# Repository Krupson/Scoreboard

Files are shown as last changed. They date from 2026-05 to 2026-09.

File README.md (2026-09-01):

# Scoreboard
An open-sourced project of digital 3D-printed scoreboard based on ESP32C6 and some WS2812 LEDs.

## Features
- Configurable colors and brightness
- Current state memory (score does not reset on power loss)
- Debounced buttons (prevents accidental add/subtract score 2nd time in very short period)
- Remote control over WiFi (Work in progress)

## Controls
### Control score
Click Tx_ADD and Tx_SUB buttons once to control score for choosen team.

### Switch sides
Double click SWITCH_SIDES button to switch sides of team 1 and team 2.

### Reset score
Double click RESET_SCORE.

## Config mode
In order to enter config mode long press SWITCH_SIDES button. While in config mode there will be "0000" displayed on the board. In order to exit config mode (and save new settings) long press SWITCH_SIDES again.

### Change brightness
While in config mode you can press and hold T1_ADD / T1_SUB buttons to increase or decrease brightness of the display.

### Change team color
While in config mode you can press Tx_ADD / Tx_SUB to change color for choosen team. Red and green should be the least power-hungry :)

## Roadmap
This project was started as something intended for our internal use. Since I am designing 3D models for this project in Fusion360 and I am beginner with this software - quality of the project is much less than acceptable. Honestly I think that the whole 3D model part needs to be recreated from scratch with use of components, project variables for some dimensions etc. 

In near future I am planning to export all STLs I have right now and create Bambu Studio project with all the parts needed to be printed split into buildplates. Then I would like to focus on firmware part, create new PCB design with its own battery and charging module (currently we use old powerbank for providing power to the device).

### Things to be done
#### General
- Create docs with parts needed to build the scoreboard
- Cleanup repo

#### 3D models
- Recreate from scratch

#### Firmware
- Get rid of Arduino project, move everything to PlatformIO project
- Review RTOS code
- Finish remote control server
- Create remote control client firmware
- Add support for temperature and humidity sensors
- Add support for SD card logging (score + temp + hum over time)

#### PCB
- Add temperture and humidity sensor
- Add SD card slot
- Add support for battery

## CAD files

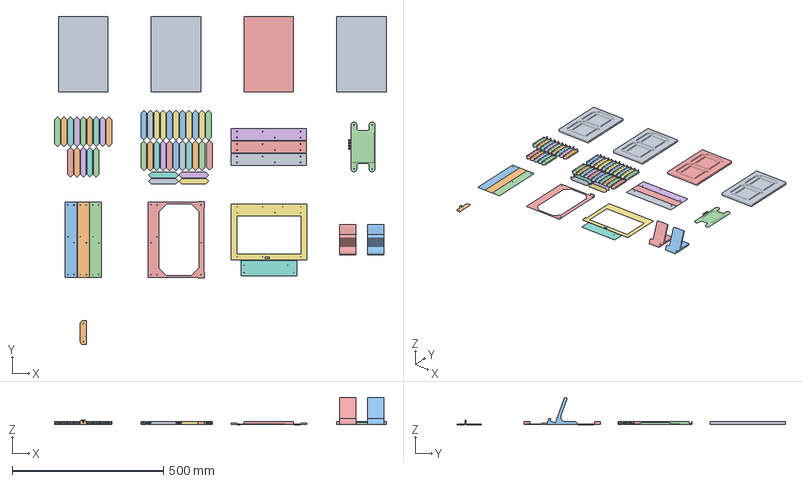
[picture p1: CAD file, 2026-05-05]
3d/Scoreboard.3mf
1098.7 x 1086.9 x 90.0 mm
Tablica wyników_Tablica wyników_Cyfra lewa.stl
antena.stl
Tablica wyników stojak_Tablica wyników_Body20.stl x 2
Tablica wyników_Tablica wyników_Obudowa sterownika.stl
dystans2_Tablica wyników_Body14.stl x 4
Tablica wyników_Tablica wyników_Szablon początek bottom.stl
Tablica wyników_Tablica wyników_Szablon kolejny bottom.stl
blenda 7seg_Tablica wyników_Blenda.stl x 40
Tablica wyników_Tablica wyników_Cyfra prawa.stl
Tablica wyników_Tablica wyników_Cyfra środek.stl
Tablica wyników_Tablica wyników_Cyfra środek sterownik.stl
Tablica wyników_Tablica wyników_Łącznik tymczasowy.stl x 3
łącznik top.stl x 3
szablon start.stl

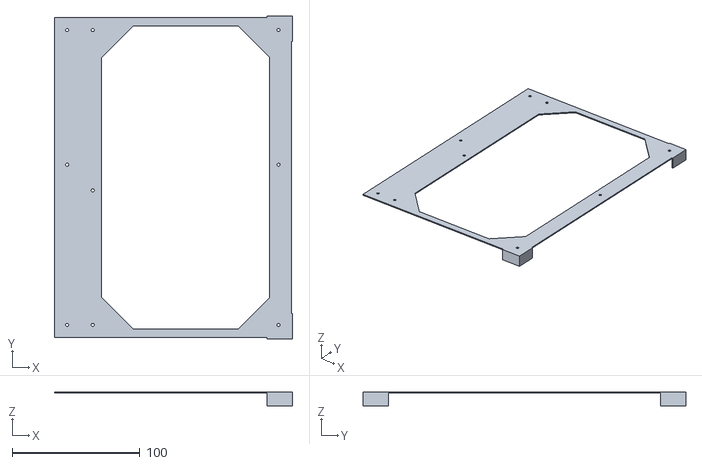
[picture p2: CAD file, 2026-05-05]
3d/stls/Scoreboard_Tablica wyników_Szablon początek top.stl
186.3 x 252.6 x 11.0

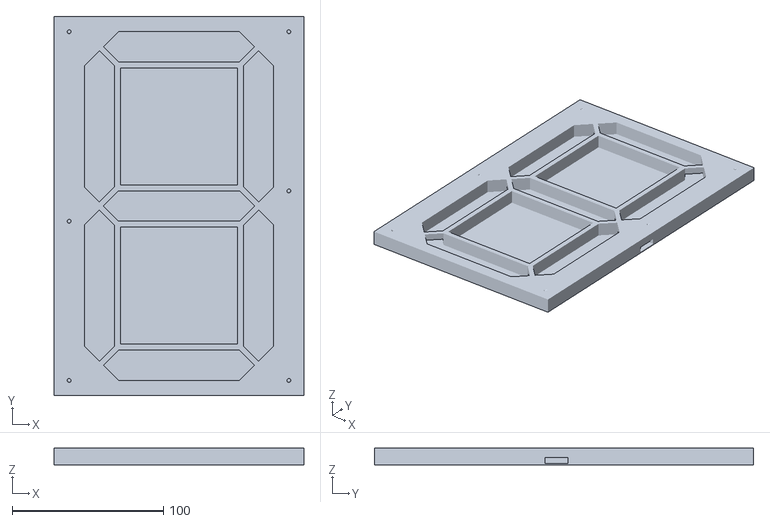
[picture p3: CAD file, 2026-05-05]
3d/stls/Scoreboard_Tablica wyników_Cyfra lewa.stl
165.3 x 250.6 x 11.0

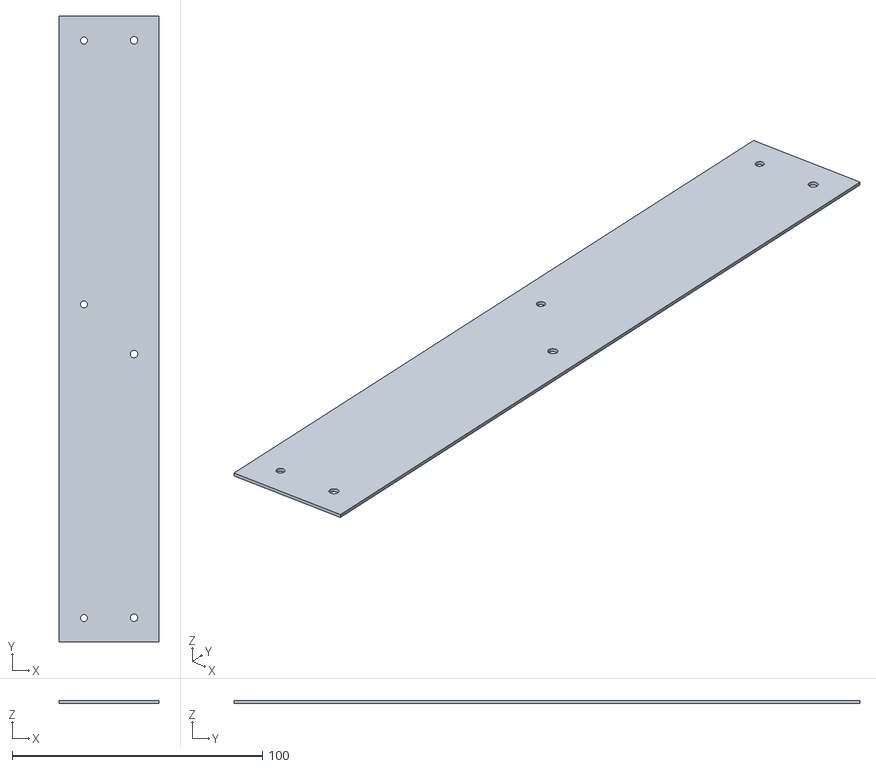
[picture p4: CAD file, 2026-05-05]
3d/stls/Scoreboard_Tablica wyników_Body15.stl
40.0 x 250.0 x 1.00

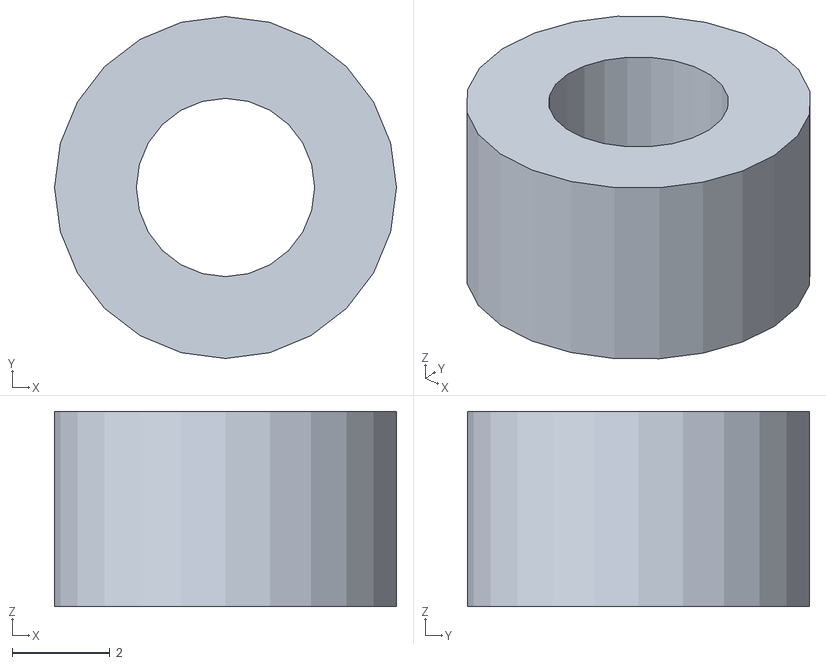
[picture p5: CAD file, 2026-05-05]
3d/stls/Scoreboard_Tablica wyników_Body12.stl
7.00 x 7.00 x 4.00

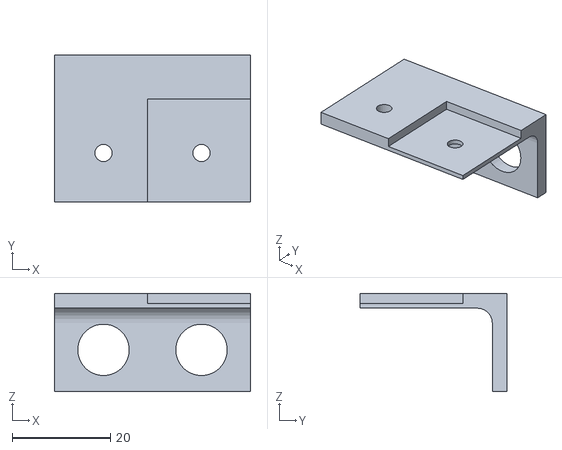
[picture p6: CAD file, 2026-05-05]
3d/stls/Scoreboard_Tablica wyników_Body22.stl
40.0 x 30.0 x 20.0

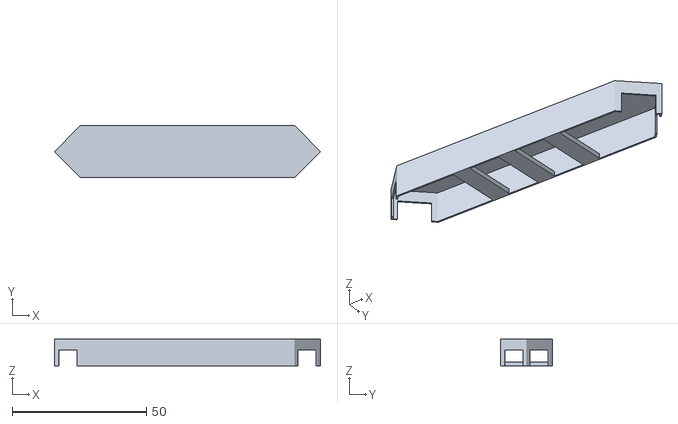
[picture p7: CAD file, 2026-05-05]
3d/stls/Scoreboard_Tablica wyników_Blenda.stl
99.2 x 19.4 x 10.0

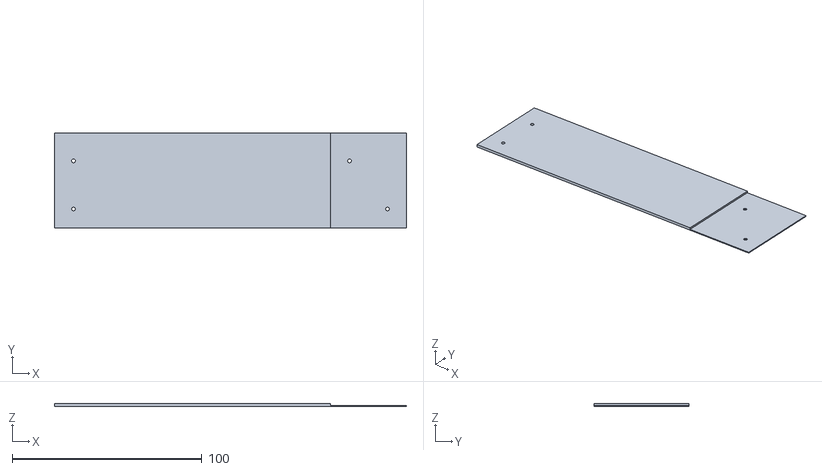
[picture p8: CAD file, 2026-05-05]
3d/stls/Scoreboard_Tablica wyników_Szablon kolejny bottom.stl
185.3 x 50.0 x 1.50

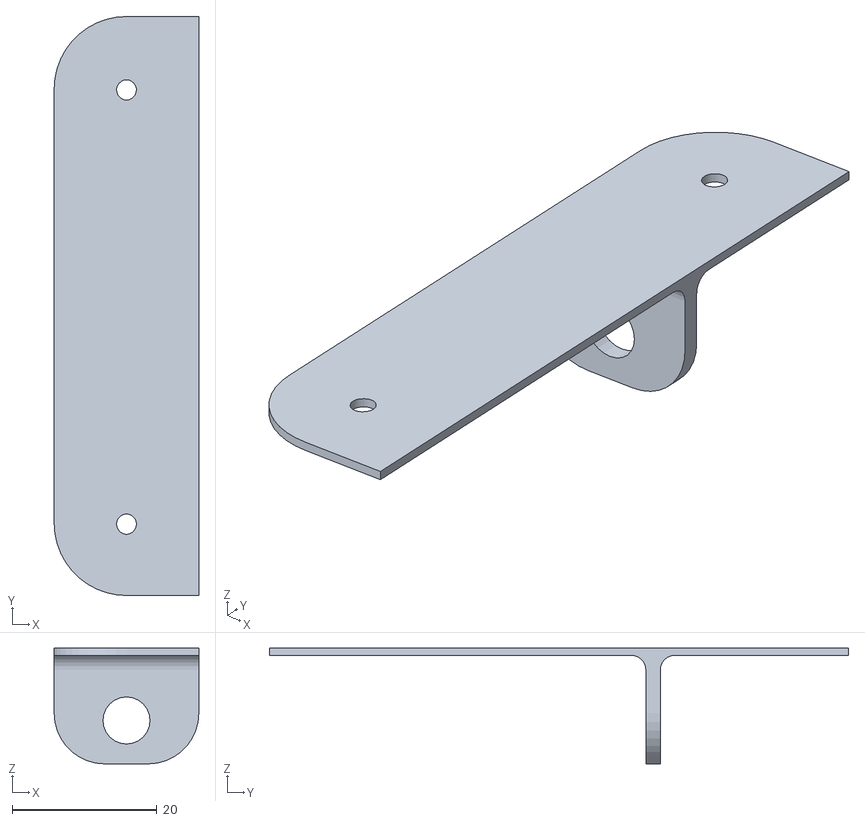
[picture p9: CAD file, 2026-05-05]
3d/stls/Scoreboard_Tablica wyników_Holder anteny.stl
20.0 x 80.0 x 16.0

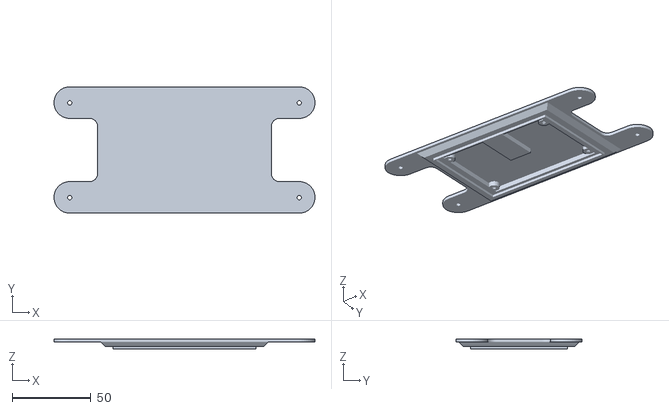
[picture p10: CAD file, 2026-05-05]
3d/stls/Scoreboard_Tablica wyników_Obudowa sterownika.stl
165.2 x 80.0 x 6.55

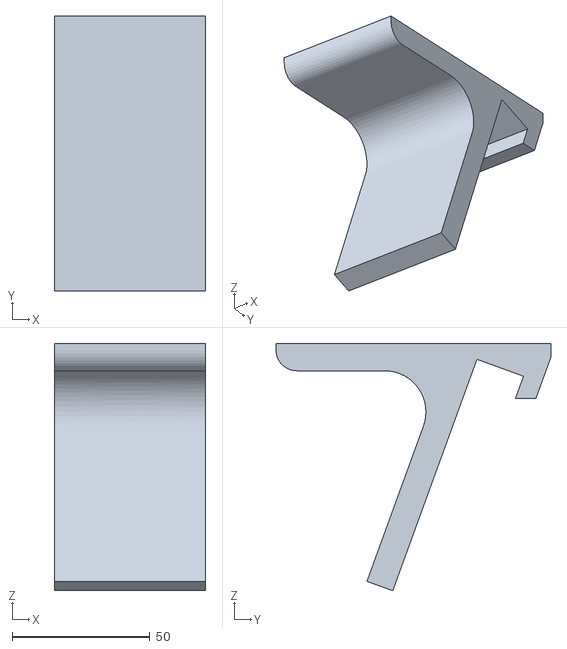
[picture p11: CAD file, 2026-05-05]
3d/stls/Scoreboard_Tablica wyników_Stojak.stl
55.0 x 100.0 x 90.0

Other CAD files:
3d/stls/Scoreboard_Tablica wyników_Body13.stl
3d/stls/Scoreboard_Tablica wyników_Cyfra środek.stl
3d/stls/Scoreboard_Tablica wyników_Cyfra środek sterownik.stl
3d/stls/Scoreboard_Tablica wyników_Body14.stl
3d/stls/Scoreboard_Tablica wyników_Cyfra prawa.stl
3d/stls/Scoreboard_Tablica wyników_Łącznik tymczasowy.stl
3d/stls/Scoreboard_Tablica wyników_Body11.stl
3d/Scoreboard.f3d
3d/stls/Scoreboard_Tablica wyników_Szablon początek bottom.stl

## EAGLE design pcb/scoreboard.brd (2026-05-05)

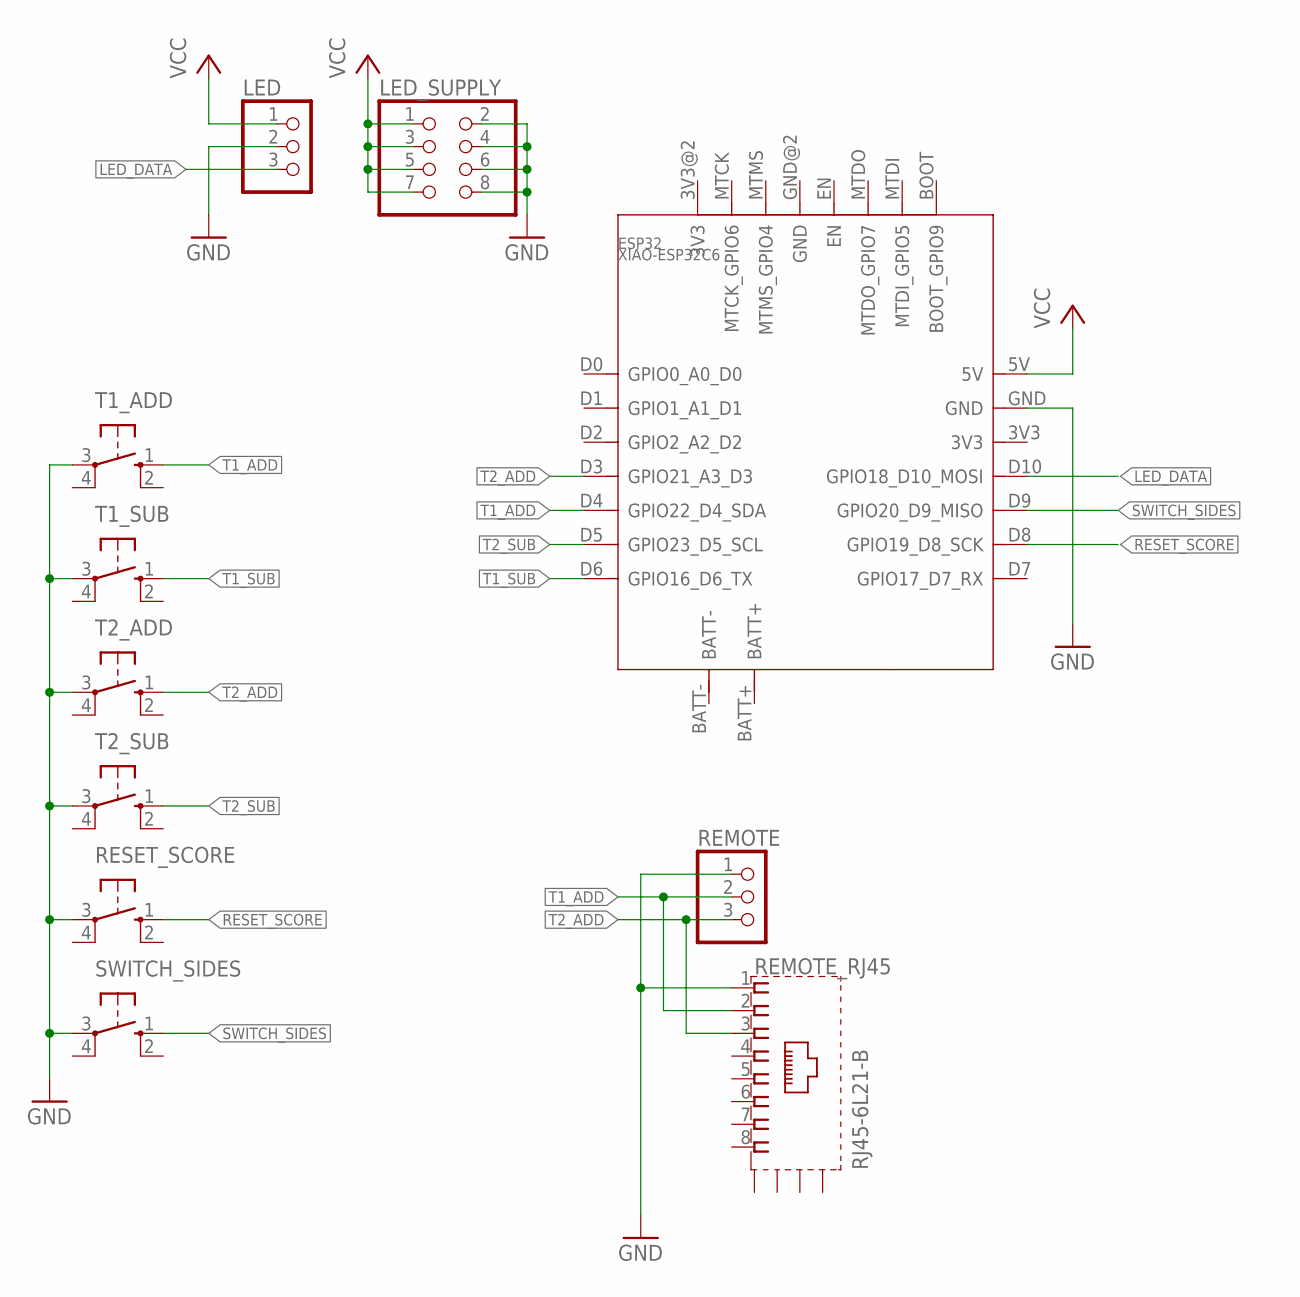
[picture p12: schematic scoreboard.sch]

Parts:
ESP32: XIAO-ESP32C6; XIAO-ESP32C6-MODULE14P-2.54-21X17.8MM
LED: PINHD-1X3; 1X03
LED_SUPPLY: PINHD-2X4; 2X04
REMOTE: PINHD-1X3; 1X03
REMOTE_RJ45: RJ45-6L21-B; RJ45-SHIELD1
RESET_SCORE: 10-XX; B3F-10XX
SWITCH_SIDES: 10-XX; B3F-10XX
T1_ADD, T1_SUB, T2_ADD, T2_SUB: 10-XX; B3F-10XX

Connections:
GND: ESP32.GND, LED.2, LED_SUPPLY.2, LED_SUPPLY.4, LED_SUPPLY.6, LED_SUPPLY.8, REMOTE.1, REMOTE_RJ45.1, RESET_SCORE.3, SWITCH_SIDES.3, T1_ADD.3, T1_SUB.3, T2_ADD.3, T2_SUB.3
LED_DATA: ESP32.D10 (GPIO18_D10_MOSI), LED.3
RESET_SCORE: ESP32.D8 (GPIO19_D8_SCK), RESET_SCORE.1 (S)
SWITCH_SIDES: ESP32.D9 (GPIO20_D9_MISO), SWITCH_SIDES.1 (S)
T1_ADD: ESP32.D4 (GPIO22_D4_SDA), REMOTE.2, REMOTE_RJ45.2, T1_ADD.1 (S)
T1_SUB: ESP32.D6 (GPIO16_D6_TX), T1_SUB.1 (S)
T2_ADD: ESP32.D3 (GPIO21_A3_D3), REMOTE.3, REMOTE_RJ45.3, T2_ADD.1 (S)
T2_SUB: ESP32.D5 (GPIO23_D5_SCL), T2_SUB.1 (S)
VCC: ESP32.5V, LED.1, LED_SUPPLY.1, LED_SUPPLY.3, LED_SUPPLY.5, LED_SUPPLY.7

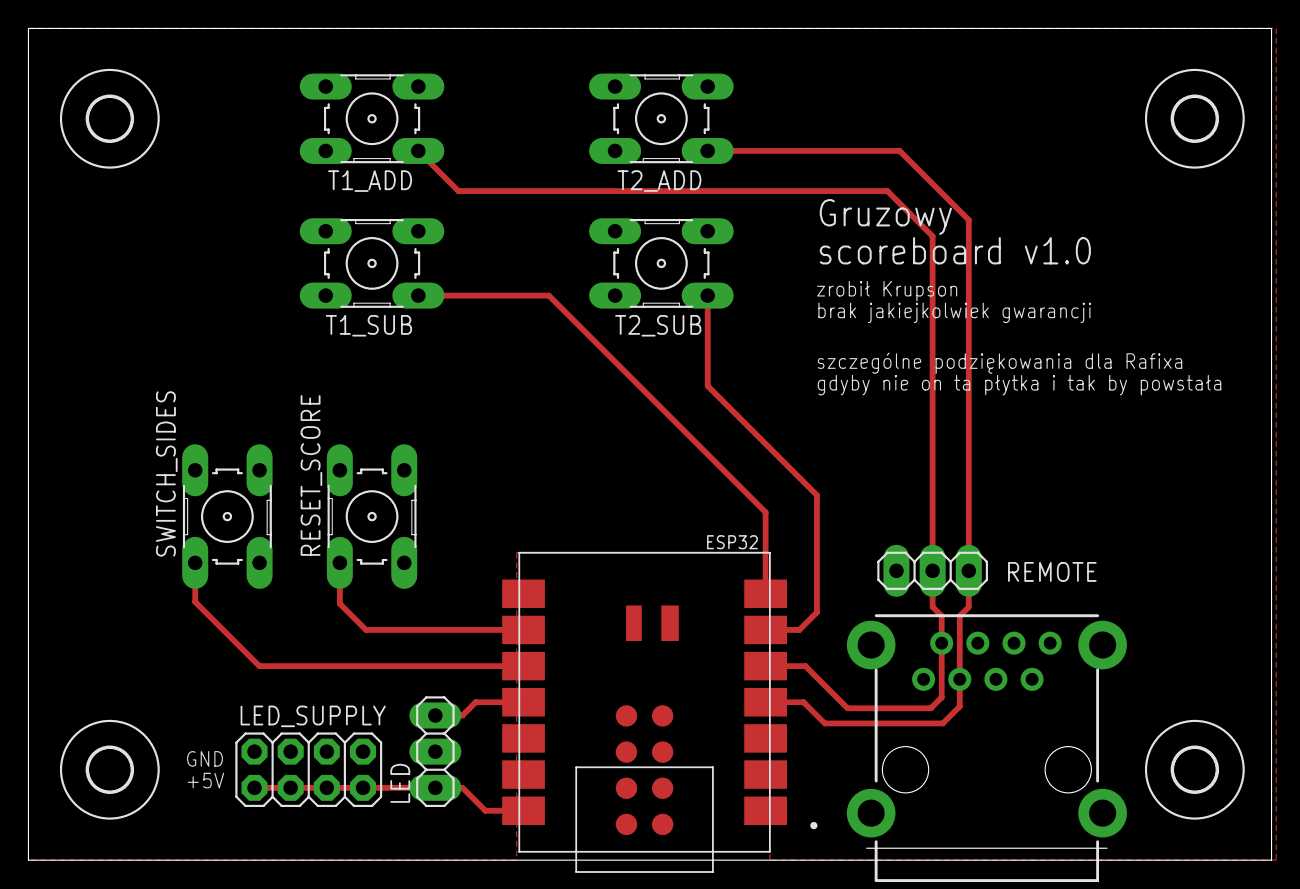
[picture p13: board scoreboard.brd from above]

Board: 2 copper layers, 87.3 x 58.4 mm, 15 parts (0 on the bottom side), 9 nets.

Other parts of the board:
U$1, U$2, U$3, U$4: 3,0

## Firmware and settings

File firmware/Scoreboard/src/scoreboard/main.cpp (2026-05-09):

#include <Arduino.h>
#include <Config.h>
#include <OneButton.h>
#include <WiFi.h>
#include <NetworkClient.h>
#include <WiFiAP.h>
#include <ESPmDNS.h>
#include <common/scoreboard/scoreboard.h>

const char *ssid = WIFI_SSID;
const char *password = WIFI_PASSWORD;

Scoreboard scoreboard;
OneButton team1AddButton;
OneButton team1SubButton;
OneButton team2AddButton;
OneButton team2SubButton;
OneButton resetScoreButton;
OneButton switchSidesButton;

NetworkServer server(SERVER_PORT);

void setupServer();
void handleServer();

void setup() {
    pinMode(WIFI_ENABLE, OUTPUT);
    digitalWrite(WIFI_ENABLE, LOW);
    delay(100);
    pinMode(WIFI_ANT_CONFIG, OUTPUT);
    digitalWrite(WIFI_ANT_CONFIG, HIGH);

    setupServer();

    team1AddButton.setup(PIN_T1_ADD, INPUT_PULLUP, true);
    team1SubButton.setup(PIN_T1_SUB, INPUT_PULLUP, true);
    team2AddButton.setup(PIN_T2_ADD, INPUT_PULLUP, true);
    team2SubButton.setup(PIN_T2_SUB, INPUT_PULLUP, true);
    resetScoreButton.setup(PIN_RESET_SCORE, INPUT_PULLUP, true);
    switchSidesButton.setup(PIN_SWITCH_SIDES, INPUT_PULLUP, true);

    team1AddButton.attachClick([]() { scoreboard.onT1Add(); });
    team1SubButton.attachClick([]() { scoreboard.onT1Sub(); });
    team2AddButton.attachClick([]() { scoreboard.onT2Add(); });
    team2SubButton.attachClick([]() { scoreboard.onT2Sub(); });

    resetScoreButton.attachDoubleClick([]() { scoreboard.onResetScore(); });
    switchSidesButton.attachDoubleClick([]() { scoreboard.onSwitchSides(); });

    switchSidesButton.attachLongPressStart([]() { scoreboard.onConfigToggle(); });

    team1AddButton.attachLongPressStart([]() { scoreboard.onBrightnessUp(); });
    team1AddButton.attachDuringLongPress([]() { scoreboard.onBrightnessUp(); });
    team1AddButton.attachLongPressStop([]() { scoreboard.onBrightnessSave(); });
    team1SubButton.attachLongPressStart([]() { scoreboard.onBrightnessDown(); });
    team1SubButton.attachDuringLongPress([]() { scoreboard.onBrightnessDown(); });
    team1SubButton.attachLongPressStop([]() { scoreboard.onBrightnessSave(); });

    scoreboard.begin();
}

void loop() {
    handleServer();
    team1AddButton.tick();
    team1SubButton.tick();
    team2AddButton.tick();
    team2SubButton.tick();
    resetScoreButton.tick();
    switchSidesButton.tick();
}

void setupServer() {
    Serial.begin(115200);
    delay(1000);
    Serial.println();
    Serial.println("Configuring access point...");

    if (!WiFi.softAP(ssid, password)) {
        log_e("Soft AP creation failed.");
        while (1);
    }
    IPAddress myIP = WiFi.softAPIP();
    Serial.print("AP IP address: ");
    Serial.println(myIP);

    if (!MDNS.begin("scoreboard")) {
        Serial.println("Error setting up MDNS responder!");
        while (1) {
            delay(1000);
        }
    }
    MDNS.addService("_http", "_tcp", SERVER_PORT);
    Serial.println("mDNS responder started.");

    server.begin();
    Serial.println("Server started");
}

void handleServer() {
    NetworkClient client = server.accept();

    if (client) {
        Serial.println("New Client.");
        String currentLine = "";
        while (client.connected()) {
            if (client.available()) {
                char c = client.read();
                Serial.write(c);
                if (c == '\n') {
                    if (currentLine.length() == 0) {
                        client.println("HTTP/1.1 200 OK");
                        client.println("Content-type:text/html");
                        client.println();

                        client.print(R"(<meta name="viewport" content="width=device-width, initial-scale=1.0">)");
                        client.print(R"(<p style="text-align: center;"><a href="/T1" style="font-size: 100px;">T1</a></p>)");
                        client.print(R"(<br><br><br><br>)");
                        client.print(R"(<p style="text-align: center;"><a href="/T2" style="font-size: 100px;">T2</a></p>)");

                        client.println();
                        break;
                    } else {
                        currentLine = "";
                    }
                } else if (c != '\r') {
                    currentLine += c;
                }

                if (currentLine.endsWith("GET /T1")) {
                    scoreboard.onT1Add();
                }
                if (currentLine.endsWith("GET /T2")) {
                    scoreboard.onT2Add();
                }
            }
        }
        client.stop();
        Serial.println("Client Disconnected.");
    }
}

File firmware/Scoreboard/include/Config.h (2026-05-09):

#pragma once

// Serial
#define SERIAL_BAUD_RATE        115200

// Network
#define WIFI_CONNECT_TIMEOUT_MS 10000
#define SERVER_PORT             80
#define WIFI_SSID               "GruzowyScoreboard"
#define WIFI_PASSWORD           "GRUZ2137"

// Scoreboard hardware
#define PIN_DATA          D10
#define PIN_T1_ADD        D4
#define PIN_T1_SUB        D6
#define PIN_T2_ADD        D3
#define PIN_T2_SUB        D5
#define PIN_RESET_SCORE   D8
#define PIN_SWITCH_SIDES  D9

// Scoreboard LEDs
#define LEDS_PER_SEGMENT                    4
#define LEDS_PER_DIGIT                      (LEDS_PER_SEGMENT * 7)
#define NUM_LEDS                            (LEDS_PER_DIGIT * 4)

// Scoreboard timing
#define MIN_SCORE_CHANGE_TIME_MS            500UL
#define MIN_BRIGHTNESS_CHANGE_TIME_MS       20UL

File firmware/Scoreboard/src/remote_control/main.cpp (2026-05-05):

#include <Arduino.h>
#include <Config.h>
#include <OneButton.h>
#include <WiFi.h>
#include <HTTPClient.h>

#define PIN_T1_ADD D8
#define PIN_T2_ADD D7

OneButton team1AddButton;
OneButton team2AddButton;

const char *ssid = WIFI_SSID;
const char *password = WIFI_PASSWORD;
//String baseUrl = "http://192.168.4.1";
String baseUrl = "http://scoreboard.local";

void onT1Add();

void onT2Add();

void reconnectWiFi();

void setup() {
    Serial.begin(SERIAL_BAUD_RATE);
    WiFi.begin(ssid, password);
    WiFi.enableLongRange(true);
    pinMode(LED_BUILTIN, OUTPUT);
    Serial.println("Connecting");
    while (WiFi.status() != WL_CONNECTED) {
        delay(500);
        digitalWrite(LED_BUILTIN, !digitalRead(LED_BUILTIN));
        Serial.print(".");
    }
    Serial.println("");
    Serial.print("Connected to WiFi network with IP Address: ");
    Serial.println(WiFi.localIP());
    digitalWrite(LED_BUILTIN, HIGH);

    team1AddButton.setup(PIN_T1_ADD, INPUT_PULLUP, true);
    team2AddButton.setup(PIN_T2_ADD, INPUT_PULLUP, true);

    team1AddButton.attachClick(onT1Add);
    team2AddButton.attachClick(onT2Add);
}

void loop() {
    team1AddButton.tick();
    team2AddButton.tick();
    if (WiFi.status() != WL_CONNECTED) {
        reconnectWiFi();
    }
}

void reconnectWiFi() {
    Serial.println("Reconnecting");
    while (WiFi.status() != WL_CONNECTED) {
        delay(500);
        digitalWrite(LED_BUILTIN, !digitalRead(LED_BUILTIN));
        Serial.print(".");
    }
    digitalWrite(LED_BUILTIN, HIGH);
}

void callServer(const String &path) {
    if (WiFi.status() == WL_CONNECTED) {
        digitalWrite(LED_BUILTIN, LOW);
        HTTPClient http;

        String serverPath = baseUrl + path;

        Serial.print("Calling endpoint: ");
        Serial.println(serverPath);

        // Your Domain name with URL path or IP address with path
        http.begin(serverPath.c_str());

        // If you need Node-RED/server authentication, insert user and password below
        //http.setAuthorization("REPLACE_WITH_SERVER_USERNAME", "REPLACE_WITH_SERVER_PASSWORD");

        // Send HTTP GET request
        int httpResponseCode = http.GET();

        if (httpResponseCode > 0) {
            Serial.print("HTTP Response code: ");
            Serial.println(httpResponseCode);
            String payload = http.getString();
            Serial.println(payload);
        } else {
            Serial.print("Error code: ");
            Serial.println(httpResponseCode);
            for (int x = 0; x < 10; x++) {
                digitalWrite(LED_BUILTIN, !digitalRead(LED_BUILTIN));
                delay(60);
            }
        }
        // Free resources
        http.end();
        digitalWrite(LED_BUILTIN, HIGH);
    } else {
        Serial.println("WiFi Disconnected");
        reconnectWiFi();
    }
}

void onT1Add() {
    Serial.println("onT1Add");
    callServer("/T1");
}

void onT2Add() {
    Serial.println("onT2Add");
    callServer("/T2");
}
